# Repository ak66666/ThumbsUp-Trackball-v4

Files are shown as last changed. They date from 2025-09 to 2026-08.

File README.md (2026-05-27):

# ThumbsUp! Trackball v4

A PCB-based finger-operated trackball, inspired by Elecom EX-G left hand trackball, Ploopy Nano trackball, and my own ThumbsUp! Trackball v3.
 
Off-the-shelf ProMicro-style MCUs is considered: 
- nice!nano v2 (and clones) with ZMK-based firmware - wireless/wired/BT/dongle.

~~34 mm ball, same as in Elecom EX-G, or~~ 44 mm, or 52.5mm as in Elecom Huge, or 55mm balls.
57mm ball may work - sensor needs to be adjusted to provide 2.4 mm distance from the lens to the ball surface.

For bearings - uxcell 2.5mm Ceramic Bearing Balls, ZrO2 Zirconium Oxide Ball, again, the same as used to improve my Elecom trackballs.
Bearings to be implanted into PCBs, no 3D-printed ball shroud/holder.

A few buttons scattered on top of the boards, not sure about their bindings yet, so let's say 6 of them at least + 4 for reset/ZMK.Studio/BT Reset/BT Next.
I.e. let's keep the buttons of v3 for now.
(As of rev.2 there are 8 "large" buttons, 3 programmable and 1 reset low-profile buttons.)

Rev.2 with 55 mm Ball: 
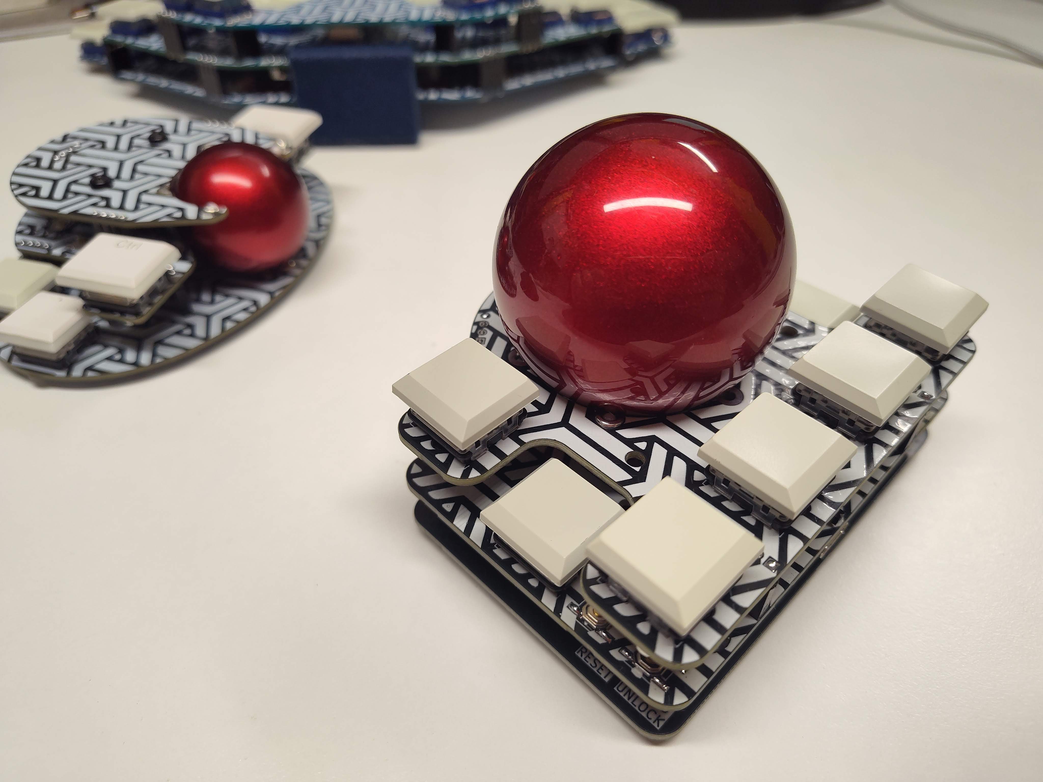
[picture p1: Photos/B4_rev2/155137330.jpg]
Photos

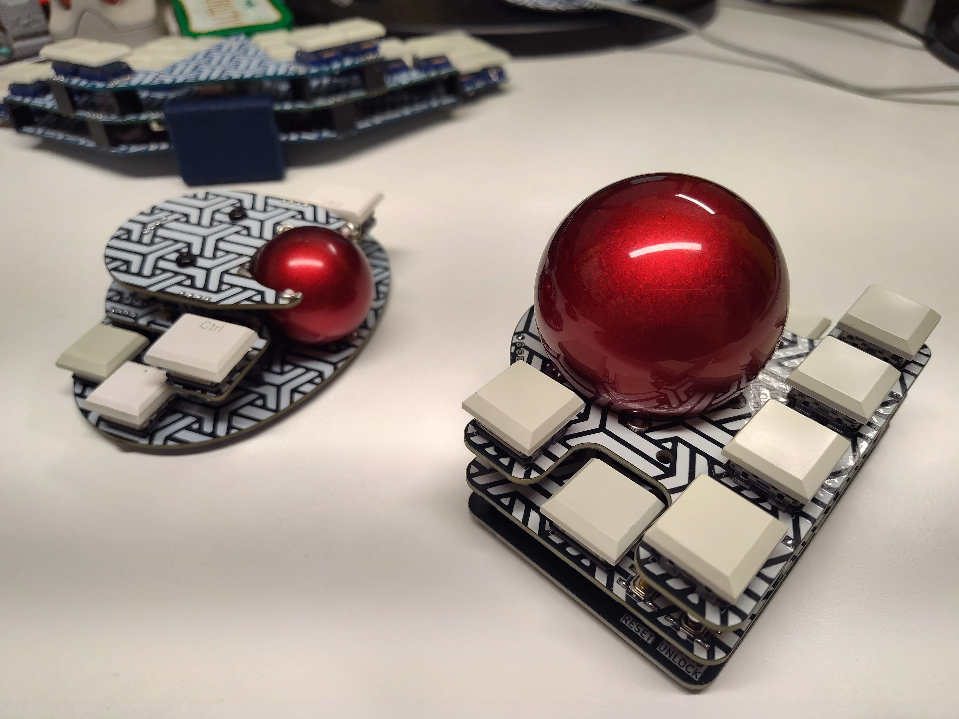
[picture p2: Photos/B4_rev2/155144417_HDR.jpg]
Photos

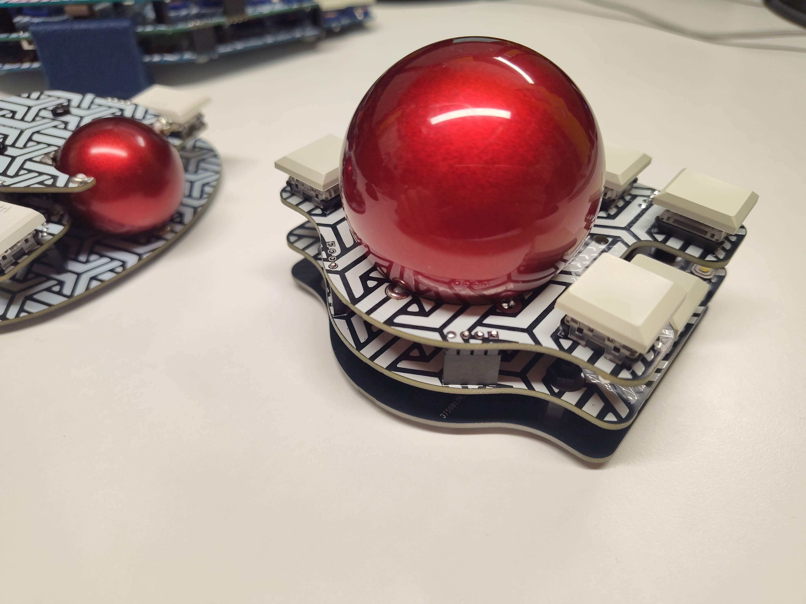
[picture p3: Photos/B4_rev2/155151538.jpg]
Photos

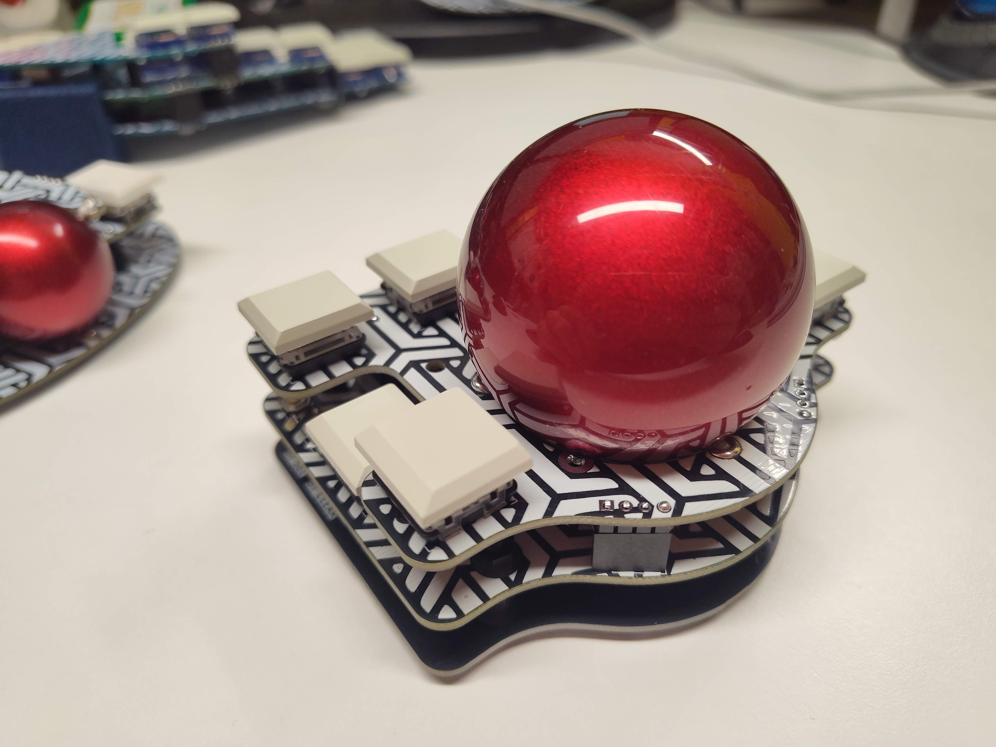
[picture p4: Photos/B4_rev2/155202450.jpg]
Photos

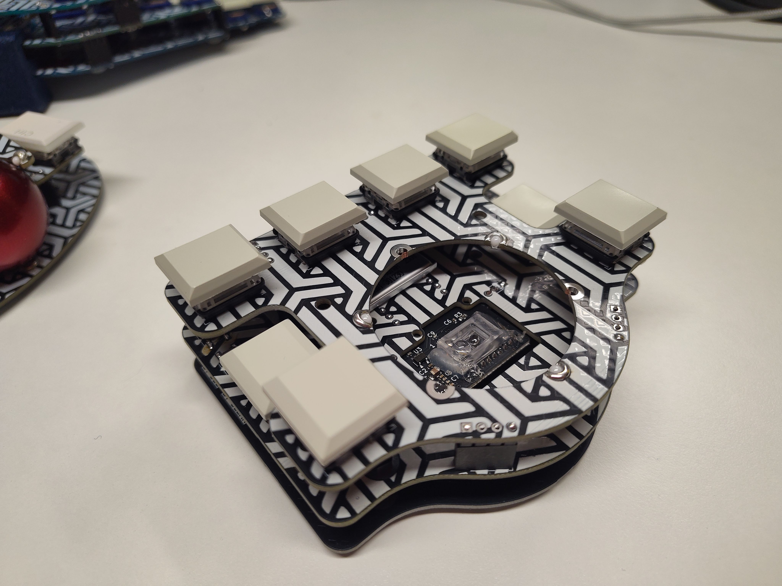
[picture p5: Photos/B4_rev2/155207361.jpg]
Photos

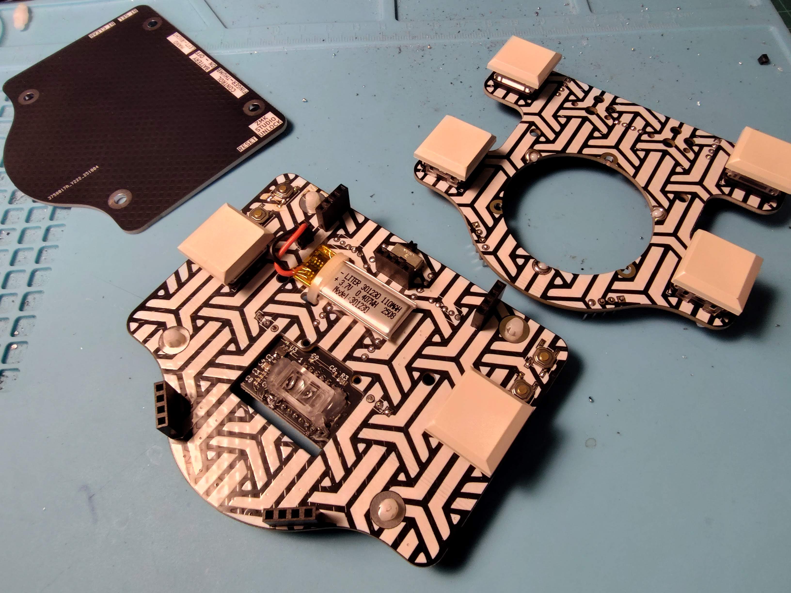
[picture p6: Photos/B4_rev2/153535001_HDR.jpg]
Photos

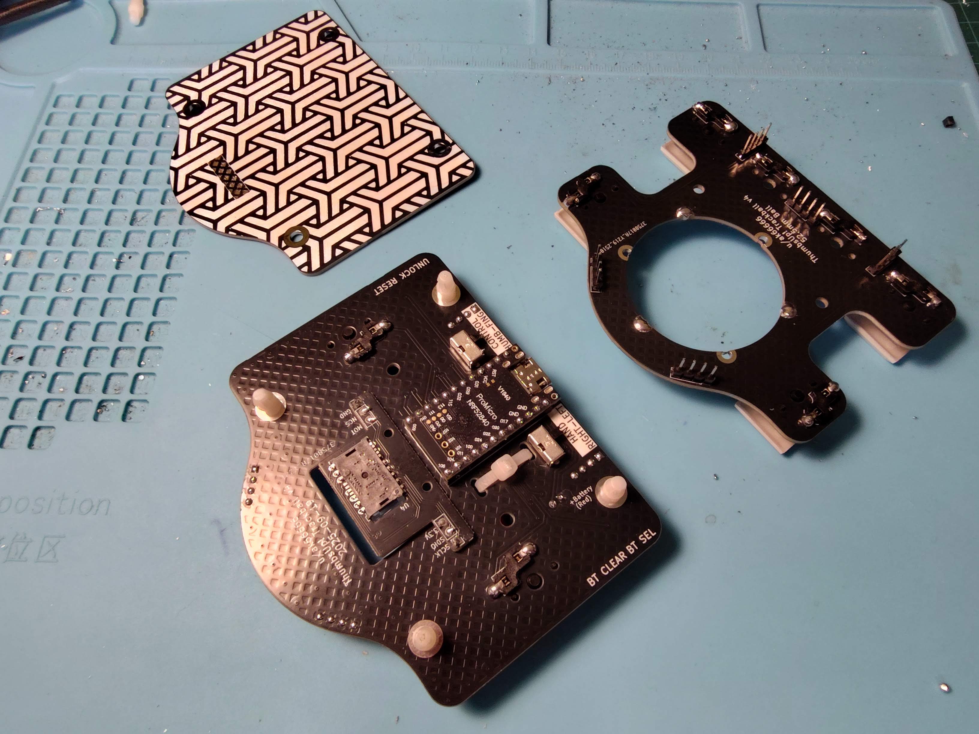
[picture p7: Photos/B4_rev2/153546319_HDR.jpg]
Photos


Rev.1 with 44 mm Ball:
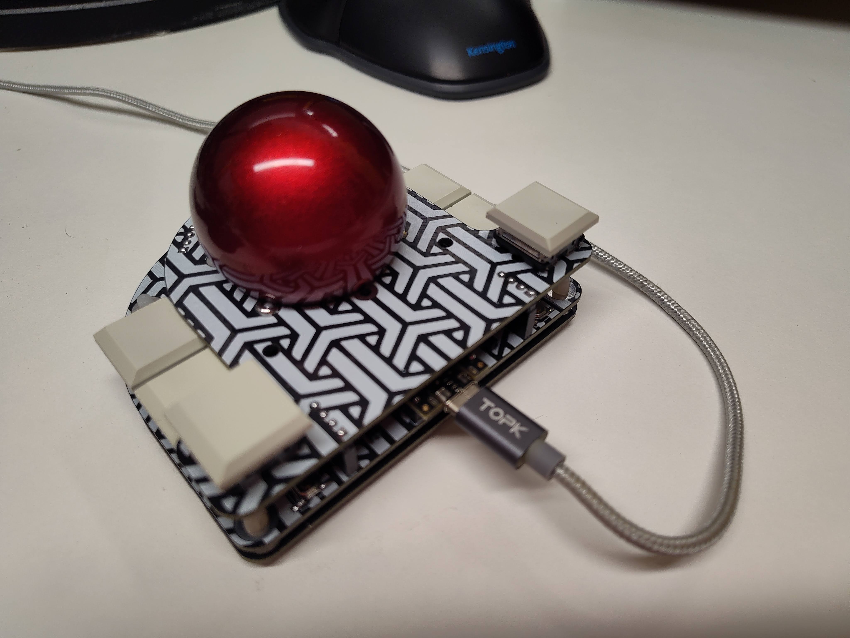
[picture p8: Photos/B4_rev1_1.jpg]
Photos

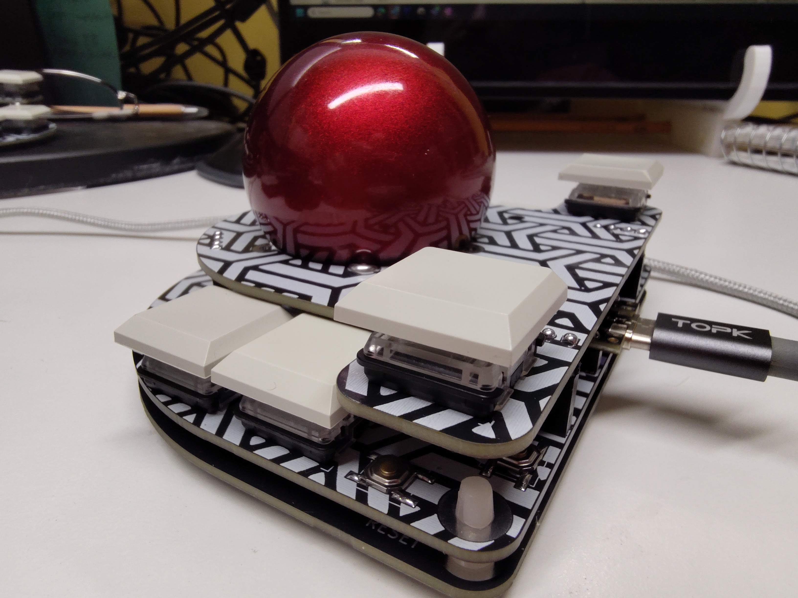
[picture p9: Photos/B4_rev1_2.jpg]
Photos

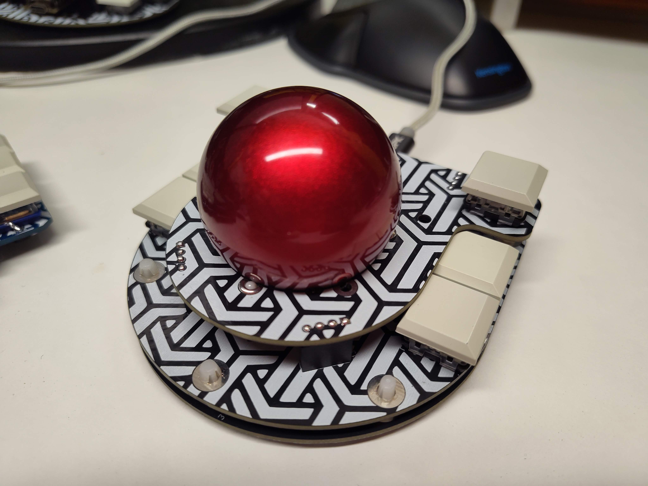
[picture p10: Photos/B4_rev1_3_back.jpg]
Photos


USB dongle (n!n in a case):
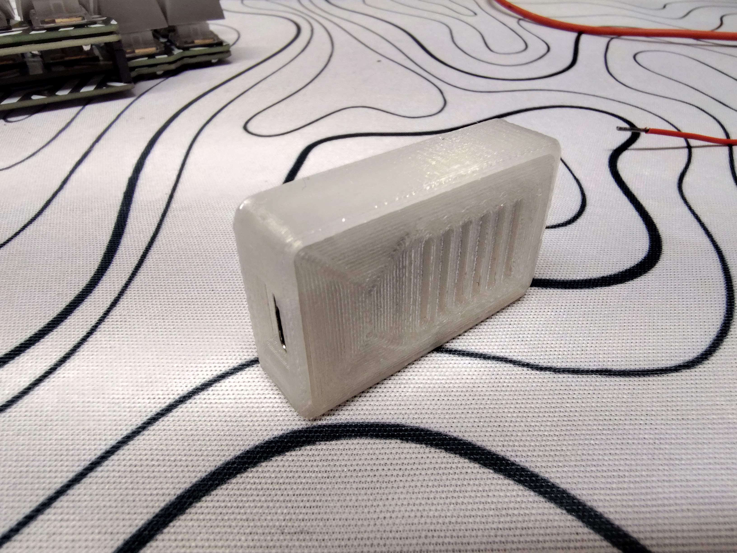
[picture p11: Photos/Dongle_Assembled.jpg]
Photos


Other pictures in Photos folder.
 
# Firmware

Bluetooth/wired connection:
https://github.com/ak66666/zmk-config-trackball.v4

USB dongle:
https://github.com/ak66666/zmk-config-trackball.v4.dongle

# For sale on Etsy
 
https://www.etsy.com/ca/listing/4390959934/thumbsup-trackball-v4-44-or-525-or-55mm

# Assembly Instructions
https://thumbsupkeyboards.blogspot.com/2025/12/thumbsup-trackball-v4-assembly-step.html

# Parts List for DYI
https://github.com/ak66666/ThumbsUp-Trackball-v4/blob/main/Kicad/Trackball/Fabrication/Trackball%20v4%2C%20Parts%20for%20DYI%2C%20Costs.xlsx

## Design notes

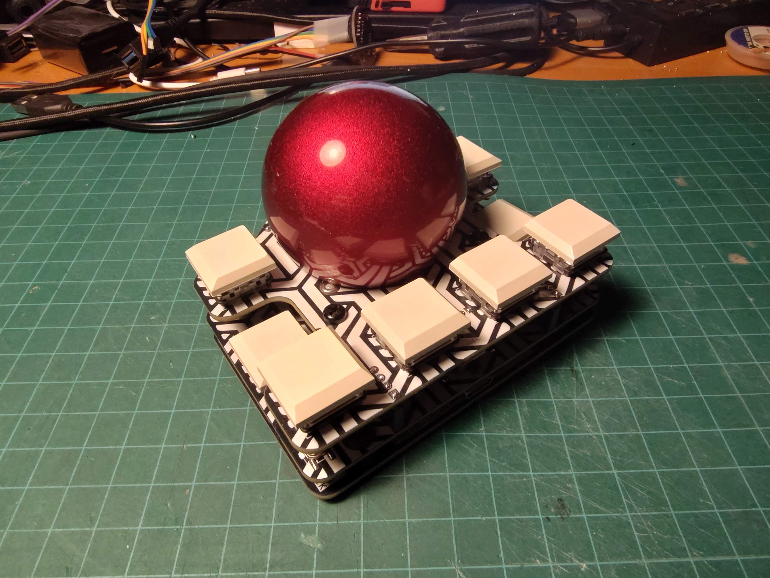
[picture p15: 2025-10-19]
Photos/B4_rev2/123444014_HDR.jpg

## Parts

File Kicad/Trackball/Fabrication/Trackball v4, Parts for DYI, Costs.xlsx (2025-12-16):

# | Part | Quantity | Price, CAD | Cost, CAD | Source
1 | PMW3610 sensor and lens | 1 | 5.99 | 5.99 | https://www.aliexpress.com/item/1005007118767775.html
2 | Nice!nano v2 (or clone) | 1 | 6.70 | 6.70 | https://www.aliexpress.com/item/1005006074191337.html
3 | 44mm ball (or 52.5mm, or 55mm) | 1 | 21.79 | 21.79 | https://www.aliexpress.com/item/1005007857787050.html
4 | 3.7V 110mAh 301230 Lithium Polymer Li-Po Battery | 1 | 2.24 | 2.24 | https://www.aliexpress.com/item/1005003662352305.html
5 | Kailh Choc hot-swap sockets | 8 | 0.19 | 1.52 | https://www.aliexpress.com/item/1005003873653184.html
6 | Kailh Choc White Clicky swithces | 8 | 1.00 | 8.00
7 | Kailh Choc Key Cap | 8 | 1.00 | 8.00
8 | 12 Pin Headers Low profile, for Nice!nano. | 2 | 0.09 | 0.19 | https://www.aliexpress.com/item/1005007217493310.html
9 | 12 Pin Sockets, Low profile, for Nice!nano. | 2 | 0.42 | 0.85 | https://www.aliexpress.com/item/1005006248653180.html
10 | 4pin Sockets and pin headers for them for the board stands. | 5 | 0.02 | 0.11 | https://www.aliexpress.com/item/1005005258694395.html
11 | 4pin Sockets and pin headers for them for the board stands. | 5 | 0.11 | 0.55 | https://www.aliexpress.com/item/1005003610333849.html
12 | 2.5mm ZrO2 Ceramic Balls | 3 | 0.51 | 1.54 | https://www.aliexpress.com/item/1005008831542121.html
13 | Slide Switches (Power, Orientation, Handiness) | 3 | 0.49 | 1.48 | https://www.mouser.ca/ProductDetail/655-1825232-1
14 | 5x5mm Tactile Switches | 4 | 0.51 | 2.05 | https://www.mouser.ca/ProductDetail/611-PTS525SKG15JSMTR
15 | 6x 8x3mm Bumpons | 6 | 0.04 | 0.26 | https://www.aliexpress.com/item/1005005287385986.html
16 | Stand-offs w/nuts | 6 | 0.10 | 0.58 | https://www.amazon.ca/dp/B0BR5MT7R1
17 | 0.5 washers | 6 | 0.09 | 0.56 | https://www.amazon.ca/dp/B0F29B674L
18 | M3 screws | 6 | 0.10 | 0.63 | https://www.amazon.ca/dp/B07C72FBZ6
19 | PCB set | 1 | 60.00 | 60.00 | Price as sold at Etsy, less if ordered 20 sets from JLCPCB by yourself
 | Total without PCBs |  | 41.41
 | Total |  | 101.41

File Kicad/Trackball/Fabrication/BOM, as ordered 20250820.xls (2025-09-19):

Comment | Designator | Footprint | JLCPCB Part #
1m | C2 | C_0402_1005Metric | C14445
3.3uF/16V | C4 | C_0805_2012Metric | C15850
10k | R3 | R_0603_1608Metric | C25804
0.1u | C3,C1,C5,C6,C8 | C_0402_1005Metric | C1525
TCR2EF19 | U3 | SOT-23-5 | C27416
0.01u | C7,C9 | C_0402_1005Metric | C15195

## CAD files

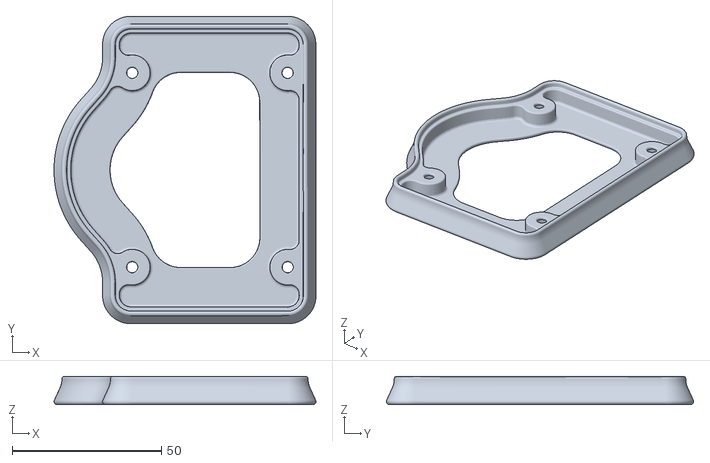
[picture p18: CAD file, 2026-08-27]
3D_parts/Base.stl
87.7 x 102.9 x 9.40

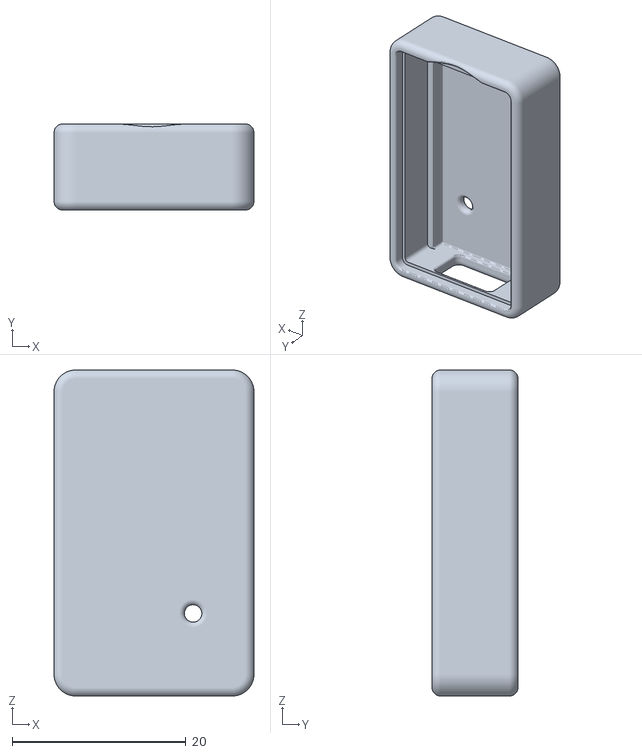
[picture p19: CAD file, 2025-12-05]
Dongle Case/Case.stl
23.0 x 9.90 x 37.5

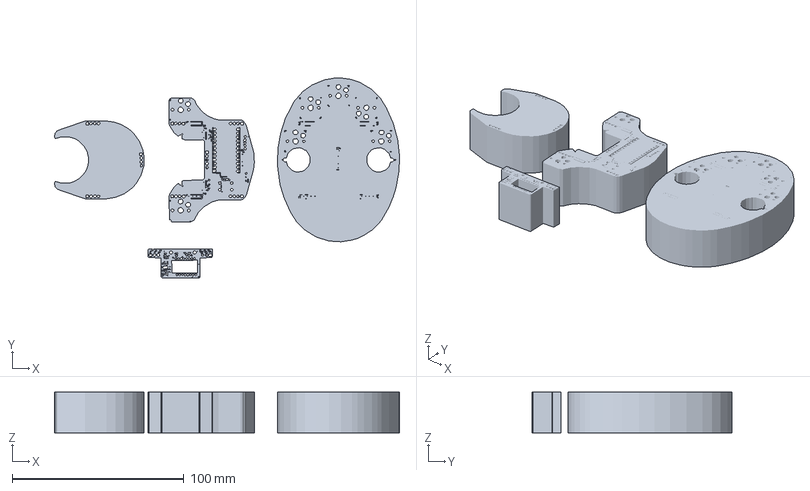
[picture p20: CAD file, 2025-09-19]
Kicad/Trackball/Pictures/PCBs.3mf
201.2 x 116.6 x 23.8 mm

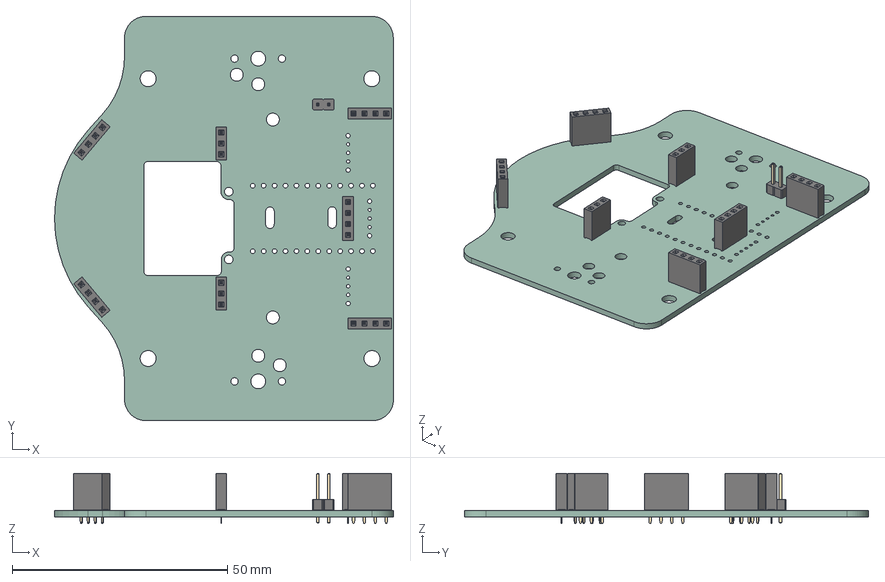
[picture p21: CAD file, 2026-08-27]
Kicad/Trackball/STL/Trackball.step
78.8 x 94.0 x 11.6 mm
PinSocket_1x04_P2.54mm_Vertical x 5
PinSocket_1x03_P2.54mm_Vertical x 2
PinHeader_1x02_P2.54mm_Vertical
Trackball_PCB

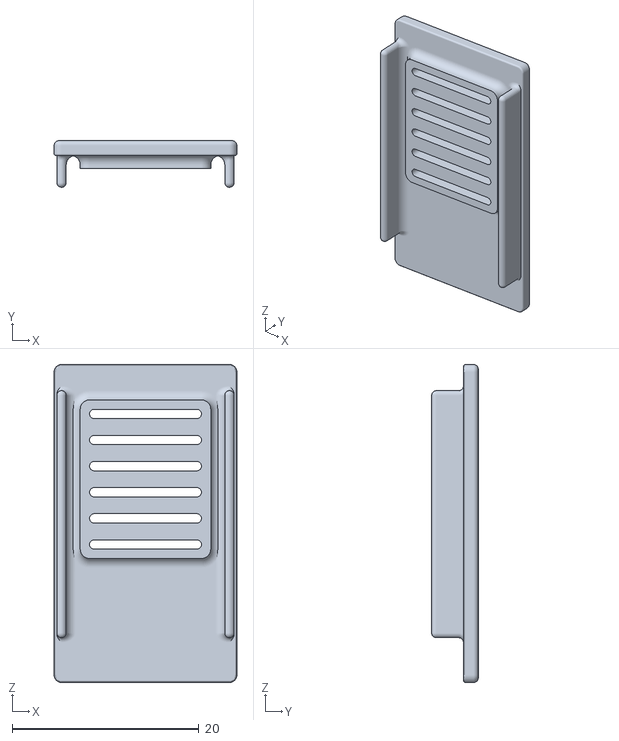
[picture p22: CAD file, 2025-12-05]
Dongle Case/Cover.stl
19.6 x 5.00 x 34.1

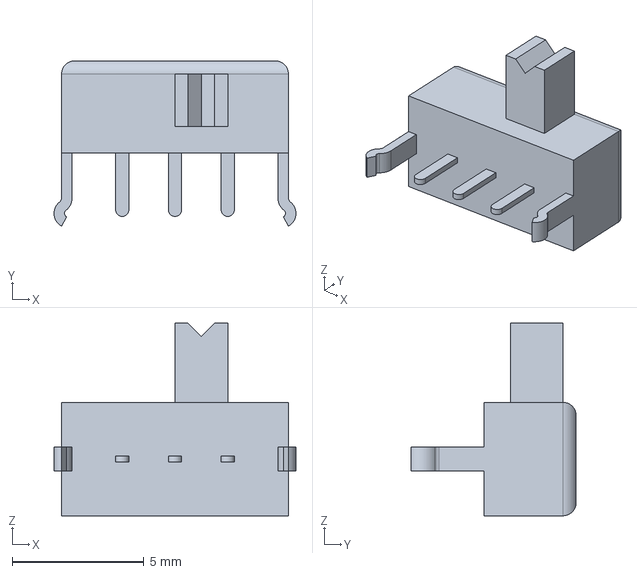
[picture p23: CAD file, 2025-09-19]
Kicad/Trackball/1825232-1/3D/1825232-1.stp
9.17 x 6.27 x 7.30 mm

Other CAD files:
Kicad/Trackball/1825232-1/Allegro/18252321.psm
Kicad/Trackball/1825232-1/DEHDL/1825232_1/chips/chips.prt

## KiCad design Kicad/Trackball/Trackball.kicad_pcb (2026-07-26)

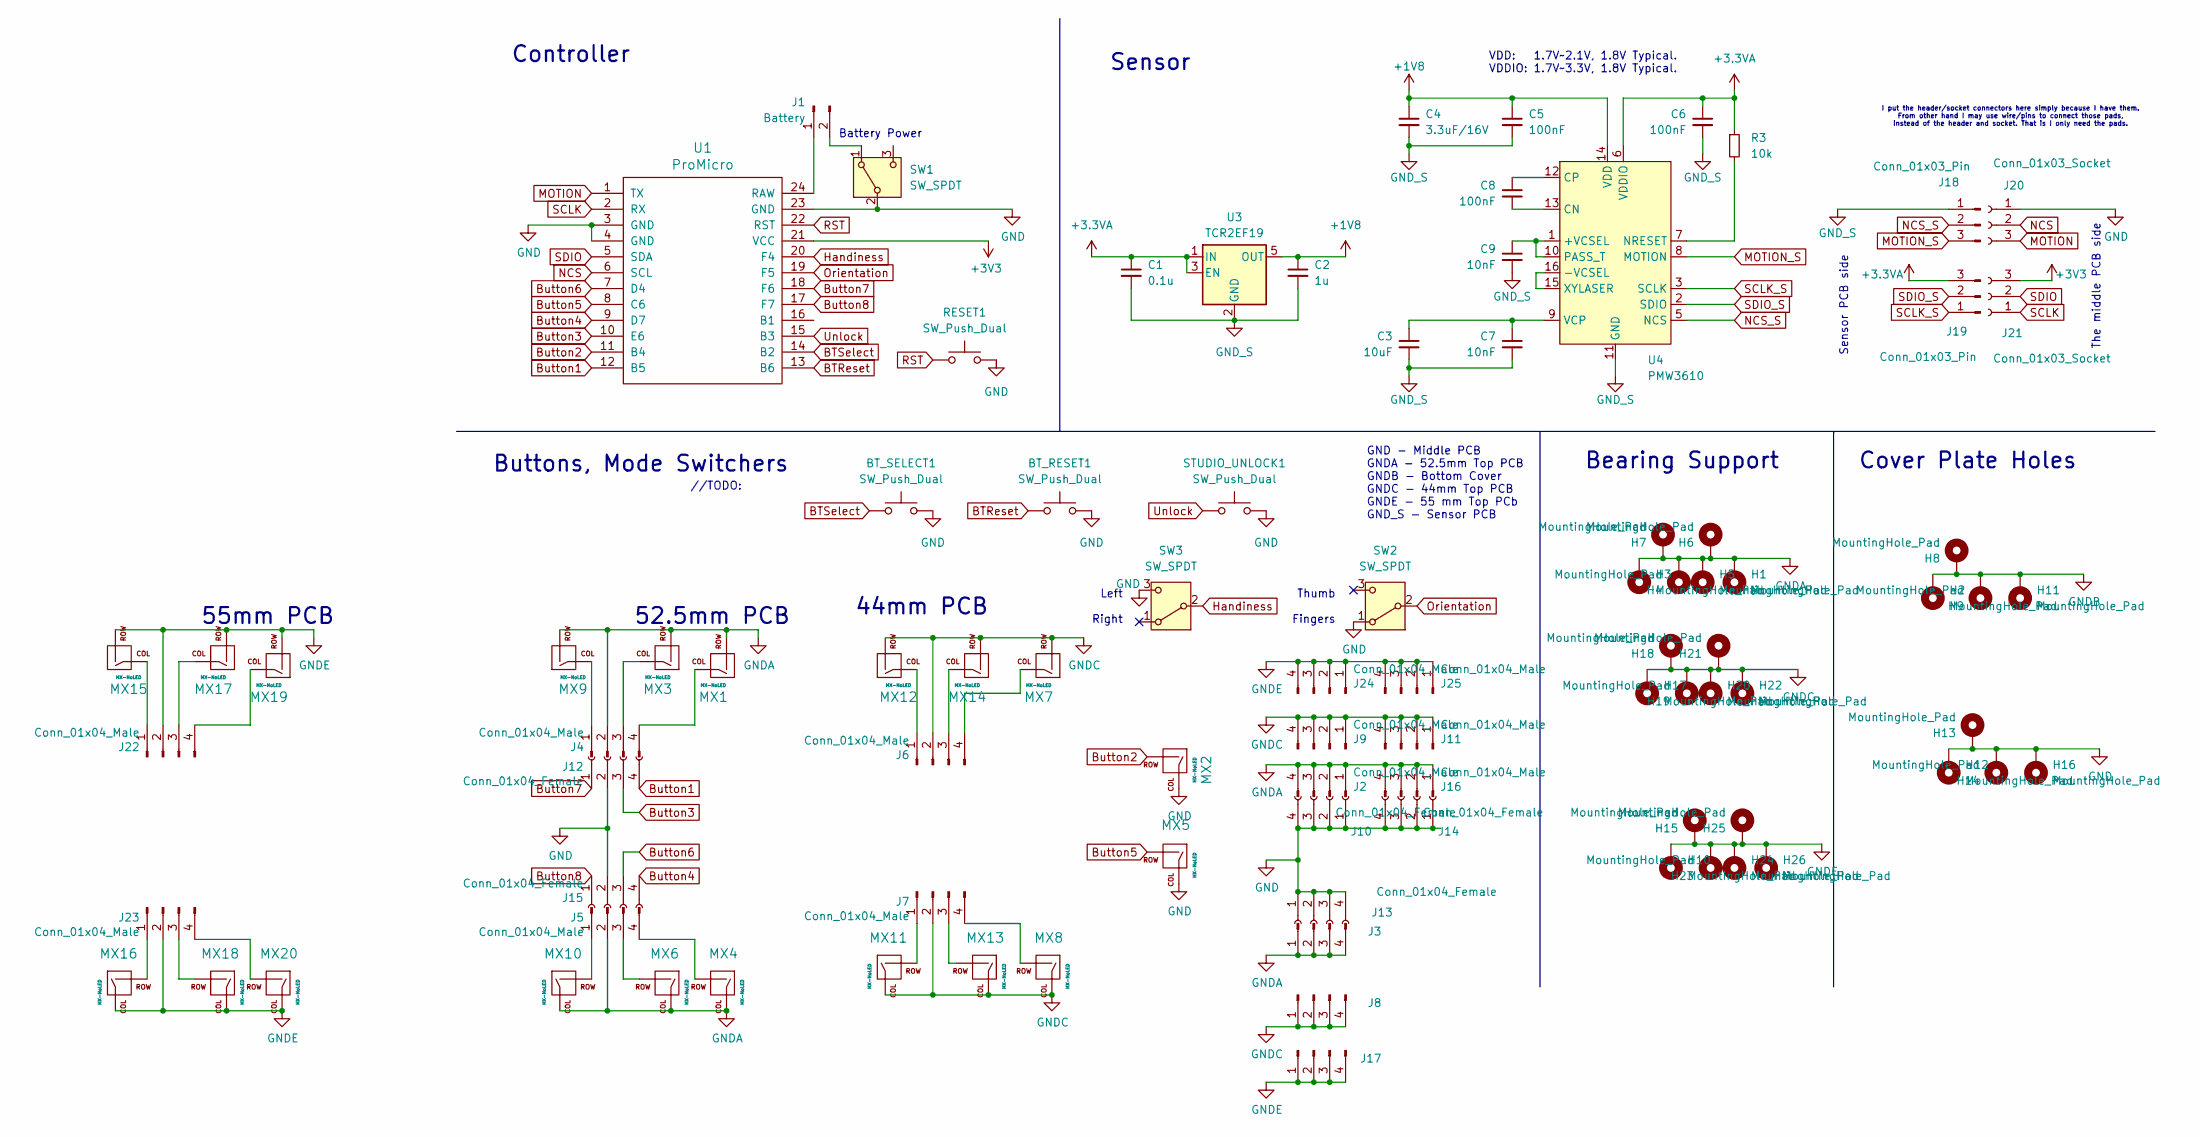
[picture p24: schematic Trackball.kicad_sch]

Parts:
BT_RESET1: SW_Push_Dual; SW_Push_1P1T_NO_CK_KSC6xxJ
BT_SELECT1: SW_Push_Dual; SW_Push_1P1T_NO_CK_KSC6xxJ
C1: 0.1u; C_0402_1005Metric
C2: 1u; C_0402_1005Metric
C3: 10uF; C_0402_1005Metric; MFR. Part # CL21A106KAYNNNE; JLCPCB Part # C15850
C4: 3.3uF/16V; C_0805_2012Metric; MFR. Part # TCC0805X7R335K250FT; JLCPCB Part # C7393948
C5, C6, C8: 100nF; C_0402_1005Metric; MFR. Part # CC0603KRX7R9BB104; JLCPCB Part # C14663
C7, C9: 10nF; C_0402_1005Metric; MFR. Part # 0603B103K500NT; JLCPCB Part # C57112
H1, H3, H4, H5, H6, H7, H10, H15, H17, H18, H19, H20, H21, H22, H23, H24, H25, H26: MountingHole_Pad; MountingHole_2.5mm_Pad
H2, H8, H9, H11, H12, H13, H14, H16: MountingHole_Pad; MountingHole_3.7mm_Pad
J1: Battery; PinHeader_1x02_P2.54mm_Vertical
J2, J3, J4, J5, J6, J7, J8, J9, J11, J16, J17, J22, J23, J24, J25: Conn_01x04_Male; PinHeader_1x04_P2.54mm_Vertical
J10, J12, J13, J14, J15: Conn_01x04_Female; PinSocket_1x04_P2.54mm_Vertical
J18, J19: Conn_01x03_Pin; PinHeader_1x03_P2.54mm_Vertical
J20, J21: Conn_01x03_Socket; PinSocket_1x03_P2.54mm_Vertical
MX1, MX2, MX3, MX4, MX5, MX6, MX7, MX8, MX9, MX10, MX11, MX12, MX13, MX14, MX15, MX16, MX17, MX18, MX19, MX20: MX-NoLED; Kailh_socket_PG1350
R3: 10k; R_0603_1608Metric; MFR. Part # 0603WAF1002T5E; JLCPCB Part # C25804
RESET1: SW_Push_Dual; SW_Push_1P1T_NO_CK_KSC6xxJ
STUDIO_UNLOCK1: SW_Push_Dual; SW_Push_1P1T_NO_CK_KSC6xxJ
SW1, SW2, SW3: SW_SPDT; 18252321
U1: ProMicro
U3: TCR2EF19; SOT-23-5
U4: PMW3610; PMW3610DM-SUDU 16Pin; MFR. Part # PMW3610DM-SUDU; JLCPCB Part # C42442560

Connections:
+1V8: C2.1, C4.1, C5.1, U3.5 (OUT), U4.14 (VDD)
+3.3VA: C1.1, C6.1, J19.3, R3.1, U3.1 (IN), U3.3 (EN), U4.6 (VDDIO)
+3V3: J21.3, U1.21 (VCC)
BTReset: BT_RESET1.1, U1.13 (B6)
BTSelect: BT_SELECT1.1, U1.14 (B2)
Button1: J12.4, U1.12 (B5)
Button2: MX2.2 (ROW), U1.11 (B4)
Button3: J12.3, U1.10 (E6)
Button4: J15.4, U1.9 (D7)
Button5: MX5.2 (ROW), U1.8 (C6)
Button6: J15.3, U1.7 (D4)
Button7: J12.1, U1.18 (F6)
Button8: J15.1, U1.17 (F7)
GND: BT_RESET1.2, BT_SELECT1.2, H12.1, H13.1, H14.1, H16.1, J10.1, J10.2, J10.3, J10.4, J12.2, J13.1, J13.2, J13.3, J13.4, J14.1, J14.2, J14.3, J14.4, J15.2, J20.1, MX2.1 (COL), MX5.1 (COL), RESET1.2, STUDIO_UNLOCK1.2, SW1.2 (B), SW2.1 (A), SW3.1 (A), SW3.3 (C), U1.3 (GND), U1.4 (GND), U1.23 (GND)
GNDA: H1.1, H3.1, H4.1, H5.1, H6.1, H7.1, J2.1, J2.2, J2.3, J2.4, J3.1, J3.2, J3.3, J3.4, J4.2, J5.2, J16.1, J16.2, J16.3, J16.4, MX1.2 (ROW), MX3.2 (ROW), MX4.1 (COL), MX6.1 (COL), MX9.2 (ROW), MX10.1 (COL)
GNDB: H2.1, H8.1, H9.1, H11.1
GNDC: H17.1, H18.1, H19.1, H20.1, H21.1, H22.1, J6.2, J7.2, J8.1, J8.2, J8.3, J8.4, J9.1, J9.2, J9.3, J9.4, J11.1, J11.2, J11.3, J11.4, MX7.2 (ROW), MX8.1 (COL), MX11.1 (COL), MX12.2 (ROW), MX13.1 (COL), MX14.2 (ROW)
GNDE: H10.1, H15.1, H23.1, H24.1, H25.1, H26.1, J17.1, J17.2, J17.3, J17.4, J22.2, J23.2, J24.1, J24.2, J24.3, J24.4, J25.1, J25.2, J25.3, J25.4, MX15.2 (ROW), MX16.1 (COL), MX17.2 (ROW), MX18.1 (COL), MX19.2 (ROW), MX20.1 (COL)
GND_S: C1.2, C2.2, C3.2, C4.2, C5.2, C6.2, C7.2, C9.2, J18.1, U3.2 (GND), U4.11 (GND)
Handiness: SW3.2 (B), U1.20 (F4)
MOTION: J20.3, U1.1 (TX)
MOTION_S: J18.3, U4.8 (MOTION)
NCS: J20.2, U1.6 (SCL)
NCS_S: J18.2, U4.5 (NCS)
unnamed: J1.1, U1.24 (RAW)
unnamed: J1.2, SW1.1 (A)
unnamed: J4.1, MX9.1 (COL)
unnamed: J4.3, MX3.1 (COL)
unnamed: J4.4, MX1.1 (COL)
unnamed: J5.1, MX10.2 (ROW)
unnamed: J5.3, MX6.2 (ROW)
unnamed: J5.4, MX4.2 (ROW)
unnamed: J6.1, MX12.1 (COL)
unnamed: J6.3, MX14.1 (COL)
unnamed: J6.4, MX7.1 (COL)
unnamed: J7.1, MX11.2 (ROW)
unnamed: J7.3, MX13.2 (ROW)
unnamed: J7.4, MX8.2 (ROW)
unnamed: J22.1, MX15.1 (COL)
unnamed: J22.3, MX17.1 (COL)
unnamed: J22.4, MX19.1 (COL)
unnamed: J23.1, MX16.2 (ROW)
unnamed: J23.3, MX18.2 (ROW)
unnamed: J23.4, MX20.2 (ROW)
unnamed: C9.1, U4.1 (+VCSEL), U4.10 (PASS_T)
unnamed: U4.15 (XYLASER), U4.16 (-VCSEL)
unnamed: C8.2, U4.13 (CN)
unnamed: C8.1, U4.12 (CP)
unnamed: R3.2, U4.7 (NRESET)
unnamed: C3.1, C7.1, U4.9 (VCP)
Orientation: SW2.2 (B), U1.19 (F5)
RST: RESET1.1, U1.22 (RST)
SCLK: J21.1, U1.2 (RX)
SCLK_S: J19.1, U4.3 (SCLK)
SDIO: J21.2, U1.5 (SDA)
SDIO_S: J19.2, U4.2 (SDIO)
Unlock: STUDIO_UNLOCK1.1, U1.15 (B3)

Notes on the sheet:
//TODO:
VDD: 1.7V~2.1V, 1.8V Typical. VDDIO: 1.7V~3.3V, 1.8V Typical.
Battery Power
I put the header/socket connectors here simply because I have them. From other hand I may use wire/pins to connect those pads, instead of the header and socket. That is I only need the pads.
Cover Plate Holes
GND - Middle PCB GNDA - 52.5mm Top PCB GNDB - Bottom Cover GNDC - 44mm Top PCB GNDE - 55 mm Top PCb GND_S - Sensor PCB
The middle PCB side
Sensor PCB side
44mm PCB
Thumb Fingers
52.5mm PCB
Buttons, Mode Switchers
Controller
Bearing Support
55mm PCB
Sensor
Left Right

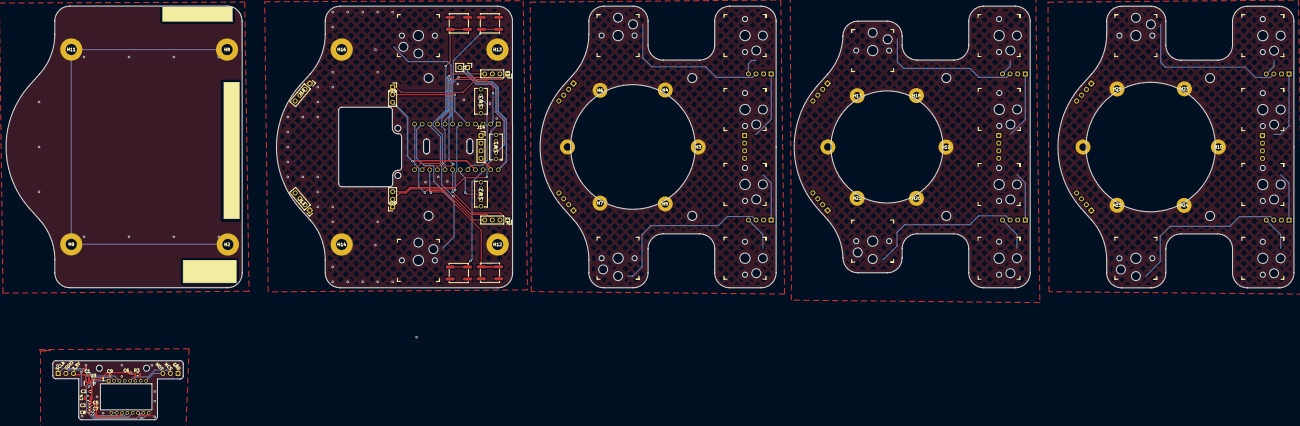
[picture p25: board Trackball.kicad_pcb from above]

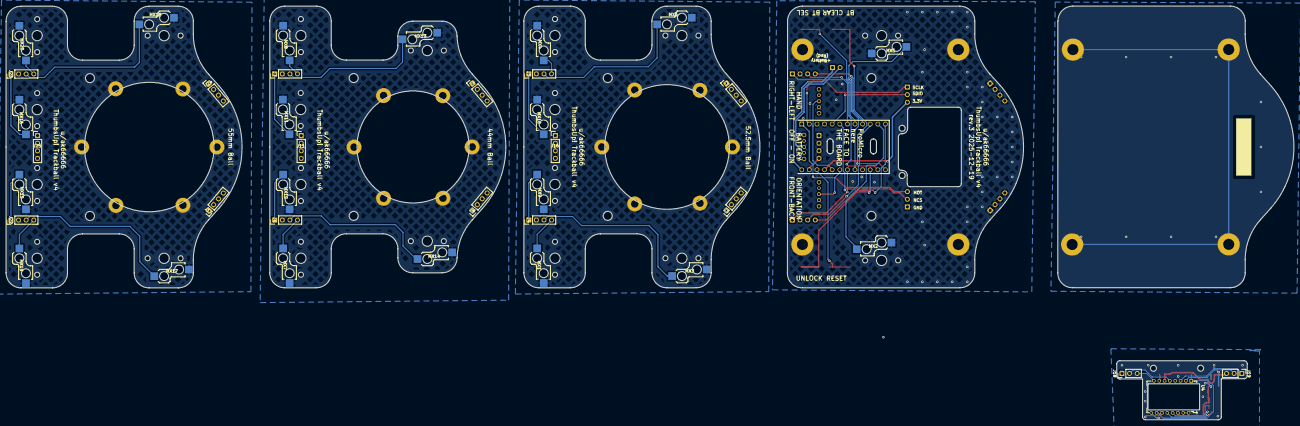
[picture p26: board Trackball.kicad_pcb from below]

Board: 2 copper layers, 429.8 x 138.1 mm, 91 parts (18 on the bottom side), 57 nets.

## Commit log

2025-09-19 B4: Project started.
    [1825232-1.SchLib, 1825232-1.stp, 18252321.PcbLib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]
2025-09-19 B4: PCB outlines defined. To do: correct schematics - swap male/female sockets, move the buttons to appropriate PCBs. Add 44mm base and the bottom cover.
    [Trackball.kicad_pcb]
2025-09-19 B4: Base, Cover, 52.5 mm ball platform ready. TODO: add 44mm platform.
    [Trackball.kicad_pcb, Trackball.kicad_sch]
2025-09-19 B4: Added 44mm platform. TODO: Prepare Gerbers for fabrication.
    [Trackball.kicad_pcb]
2025-09-19 B4: Corrected labels on the protective cover. TODO: Prepare Gerbers for fabrication.
    [Trackball.kicad_pcb]
2025-09-19 B4: Gerbers prepared.
    [Trackball-B_Cu.gbr, Trackball-B_Mask.gbr, Trackball-B_Paste.gbr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]
2025-09-19 B4: Renamed Gerbers to distinguish them from v3
2025-09-19 B4: Trying to hoax JLC to think the bottom plate is small - added pad holes instead of simple holes.
    [Trackball-B_Cu.gbr, Trackball-B_Mask.gbr, Trackball-B_Paste.gbr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]
2025-09-19 B4: Corrected the labels that were covered by the new pads.
    [Trackball-B_Cu.gbr, Trackball-B_Mask.gbr, Trackball-B_Paste.gbr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]
2025-10-01 B4: Corrected the PCBs, added two more keys. TODO: add 55mm top deck.
    [Trackball-B_Cu.gbr, Trackball-B_Mask.gbr, Trackball-B_Paste.gbr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]
2025-10-02 B4: Added 55mm top PCB, moved the buttons around, reduced the overall outline. TODO: lay out the wiring.
    [Trackball.kicad_pcb, Trackball.kicad_sch]
2025-10-03 B4: Wired all the layers. TODO: generate Gerbers.
    [Trackball-B_Cu.gbr, Trackball-B_Mask.gbr, Trackball-B_Paste.gbr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]
2025-10-03 B4: Flipped n!n to the back side, facing up - to the board.
    [Trackball-B_Cu.gbr, Trackball-B_Mask.gbr, Trackball-B_Paste.gbr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]
2025-10-03 B4: Regenerated Gerbers for the middle and bottom decks, sent for manufacturing.
    [Trackball-B_Cu.gbr, Trackball-B_Mask.gbr, Trackball-B_Paste.gbr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]
2025-10-03 Update README.md
    Added 55mm ball, removed 34mm mention
2025-10-03 B4: Added photos of rev.1 device.
2025-12-05 B3: Replaced the dongle files.
    [Case.stl, Cover.stl]
2025-12-16 B4: Added DYI part list.
    [Trackball v4, Parts for DYI, Costs.xlsx]
2025-12-18 B4: Corrected orientation switch labels, moved the battery tie-down holes to its center. TODO: recreate Gerbers.
    [Trackball.kicad_pcb]
2025-12-18 B4: Recreated gerbers for the two bottom PCBs, ordered them 2025-12-18.
    [Trackball-B_Cu.gbr, Trackball-B_Mask.gbr, Trackball-B_Paste.gbr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]
2025-12-19 B4: Moved the ball size label to a place readable in assembled unit.
    [Trackball.kicad_pcb]
2025-12-19 B4: Added copper layer under the labels on the two bottom PCBs. TODO: regenerate all Gerbers.
    [Trackball.kicad_pcb]
2026-03-26 Revise assembly instructions for Trackball v4
    Updated assembly instructions and removed outdated link.
2026-07-07 B4: Uploaded the latest working firmware, with ZMK.studio allowing specific mouse button selection.
2026-07-26 B4: Re-generated bottom plate to use solid fill zone, and to get the labels shown through the silklayers.
    [Trackball-B_Cu.gbr, Trackball-B_Mask.gbr, Trackball-B_Paste.gbr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]
2026-08-27 B4: Added a 3D printed base to replace the bottom plate.
    [Base.stl, Trackball.step]
